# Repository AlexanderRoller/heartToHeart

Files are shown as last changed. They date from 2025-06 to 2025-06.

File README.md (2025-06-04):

# HeartToHeart

HeartToHeart is a hardware project designed for IoT prototyping, featuring a custom PCB and ESP32 microcontroller. The project includes AWS IoT integration, a custom display, and a complete KiCad design for fabrication and assembly.

## Features
- Custom PCB design (KiCad)
- ESP32 microcontroller
- AWS IoT Core connectivity
- OLED display (NHD-C12832A1Z-FSW-FBW-3V3)
- Example firmware for secure WiFi and AWS IoT connection

## Directory Structure
- `pcb/` – KiCad project files and backups
- `src/` – Firmware source code and secrets templates
- `pcb/media/` – Project images and schematic PDF

## Getting Started
1. **Clone the repository**
2. Copy `src/secrets.example.h` to `src/secrets.h` and fill in your WiFi and AWS IoT credentials
3. Open `pcb/pcb.kicad_pro` in KiCad to view or modify the PCB
4. Generate your own fabrication files (Gerbers, drills, etc.) using KiCad's plot and export tools
5. Flash the firmware in `src/src.ino` to your ESP32

## Images

### PCB Layout
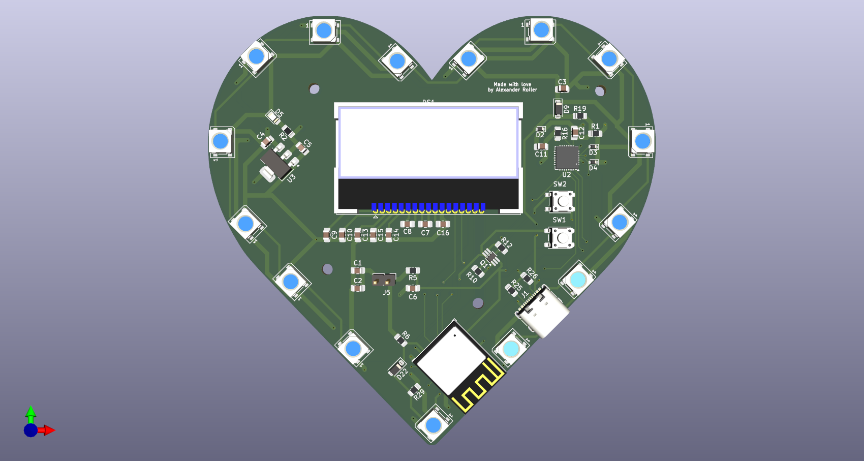
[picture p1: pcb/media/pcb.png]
PCB Layout


### Schematic
Schematic

## License
See `pcb/License.txt` for licensing information.

---

**Note:** Do not commit your real `src/secrets.h` with credentials. Use `src/secrets.example.h` as a template.

**Important:** Fabrication files (Gerbers, drills, etc.) are not included in the repository. You must generate your own using the provided KiCad project files.

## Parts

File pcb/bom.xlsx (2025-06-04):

Country of Origin may be different at time of shipment.
The HTSUS and ECCN information shown is for informational purposes only and is not a representation or warranty as to the accuracy or reliability of these classifications. All information is provided "as is" and is subject to change without notice. Any use made of the information provided is without recourse to Digi-Key and at the user's risk.
Index | Manufacturer Part Number | Manufacturer Name | Description | Availability | Stock Status | Attrition % | Requested Quantity 1 | Pack Quantity 1 | Pack Type 1 | Digi-Key Part Number 1 | Unit Price 1 | Extended Price 1 | Minimum Order Quantity 1 | Customer Reference | Requested Part Number | Lead Weeks | Datasheet | Reference Designator | US Import Tariff | Note | Part Status | RoHS Status | Moisture Sensitivity Level (MSL) | ECCN | HTSUS | Country of Origin | Environmental Information | Original Part numbers | REACH Status | Unit of Measure | Image | Product Notes
1 | ESP32-C6-MINI-1-N4 | Espressif Systems | RF TXRX MOD BT WIFI PCB TH SMD | 3,475 | In Stock |  | 1 | 1 | Cut Tape (CT) | 1965-ESP32-C6-MINI-1-N4CT-ND | 4.40000 | $4.40 | 1 |  | 1965-ESP32-C6-MINI-1-N4TR-ND | 8 | https://www.espressif.com/sites/default/files/documentation/esp32-c6-mini-1_mini-1u_datasheet_en.pdf |  | May apply on shipments to the U.S. |  | Active | Unknown | 3 (168 Hours) | 5A992C SC | 8517.62.0090 | China |  | 1965-ESP32-C6-MINI-1-N4TR-ND |  | EACH | https://mm.digikey.com/Volume0/opasdata/d220001/medias/images/4908/MFG_ESP32-C6-MINI-1-N4.jpg
2 | USB4105-GF-A | GCT | CONN RCP USB2.0 TYP C 24P SMD RA | 97,778 | In Stock |  | 1 | 1 | Cut Tape (CT) | 2073-USB4105-GF-ACT-ND | 0.78000 | $0.78 | 1 |  | 2073-USB4105-GF-ATR-ND | 9 | https://mm.digikey.com/Volume0/opasdata/d220001/medias/docus/5492/USB4105.pdf |  | May apply on shipments to the U.S. |  | Active | ROHS3 Compliant | 1 (Unlimited) | EAR99 | 8536.69.4040 | China | https://gct.co/files/info/gct_certificate_of_compliance.pdf | 2073-USB4105-GF-ATR-ND | REACH Unaffected | EACH | https://mm.digikey.com/Volume0/opasdata/d220001/medias/images/199/MFG_USB4105-GF-A.jpg
3 | 16347 | SparkFun Electronics | ADDRESS LED RED/GRN/BLUE | 34,175 | In Stock |  | 15 | 15 | Cut Tape (CT) | 1568-16347CT-ND | 0.68000 | $10.20 | 1 |  | 1568-16347TR-ND | 5 | https://cdn.sparkfun.com/datasheets/BreakoutBoards/WS2812B.pdf |  | N/A |  | Active | ROHS3 Compliant | 5A (24 Hours) | EAR99 | 8539.51.0000 | China |  | 1568-16347TR-ND | REACH Unaffected | EACH | https://mm.digikey.com/Volume0/opasdata/d220001/medias/images/4004/COM-16347.jpg
4 | BC847BDW1T1G | onsemi | TRANS 2NPN 45V 100MA SC88/SC70 | 135,970 | In Stock |  | 1 | 1 | Cut Tape (CT) | BC847BDW1T1GOSCT-ND | 0.18000 | $0.18 | 1 |  | BC847BDW1T1GOSCT-ND | 10 | https://www.onsemi.com/pdf/datasheet/bc846bdw1t1-d.pdf |  | May apply on shipments to the U.S. |  | Active | ROHS3 Compliant | 1 (Unlimited) | EAR99 | 8541.21.0075 | China | https://www.onsemi.com/site/pdf/RoHS-statement.pdf|https://www.onsemi.com/site/pdf/REACH-compliance-statement.pdf|https://www.onsemi.com/PowerSolutions/MaterialComposition.do?export=pdf&opnId=BC847BDW1T1G | BC847BDW1T1GOSCT-ND | REACH Unaffected | EACH | https://mm.digikey.com/Volume0/opasdata/d220001/medias/images/5883/488%7E419B-02%7EDF%2CDW%2CSQ%7E6-View-2.jpg
5 | CP2102N-A02-GQFN28 | Silicon Labs | IC USB TO UART BRIDGE QFN28 | 2,485 | In Stock |  | 1 | 1 | Tube | 336-5889-ND | 4.32000 | $4.32 | 1 |  | 336-5889-ND | 12 | https://www.silabs.com/documents/public/data-sheets/cp2102n-datasheet.pdf |  | N/A |  | Active | ROHS3 Compliant | 2 (1 Year) | EAR99 | 8542.39.0060 | Thailand |  | 336-5889-ND | REACH Unaffected | EACH | https://mm.digikey.com/Volume0/opasdata/d220001/medias/images/6222/336%7E28QFN-.80-5X5%7E%7E28.jpg
6 | AZ1117CH-3.3TRG1 | Diodes Incorporated | IC REG LINEAR 3.3V 1A SOT-223-3 | 39,920 | In Stock |  | 1 | 1 | Cut Tape (CT) | AZ1117CH-3.3TRG1DICT-ND | 0.16000 | $0.16 | 1 |  | AZ1117CH-3.3TRG1DITR-ND | 12 | https://www.diodes.com/assets/Datasheets/AZ1117C.pdf |  | May apply on shipments to the U.S. |  | Active | ROHS3 Compliant | 3 (168 Hours) | EAR99 | 8542.39.0060 | China | https://mm.digikey.com/Volume0/opasdata/d220001/medias/docus/6731/Diode%20RoHS3%20REACH%20247%20Jan%202025%20Statement.pdf | AZ1117CH-3.3TRG1DITR-ND | REACH Unaffected | EACH | https://mm.digikey.com/Volume0/opasdata/d220001/medias/images/4895/31%7ESOT223%7EE%2CG%2CH%7E4.JPG
7 | NHD-C12832A1Z-FSW-FBW-3V3 | Newhaven Display Intl | GRAPHIC DISPLAY FSTN BLACK (WHIT | 6,824 | In Stock |  | 1 | 1 | Bulk | NHD-C12832A1Z-FSW-FBW-3V3-ND | 12.78000 | $12.78 | 1 |  | NHD-C12832A1Z-FSW-FBW-3V3-ND | 18 | https://newhavendisplay.com/content/specs/NHD-C12832A1Z-FSW-FBW-3V3.pdf |  | May apply on shipments to the U.S. |  | Active | ROHS3 Compliant | Not Applicable | EAR99 | 8524.91.1000 | China |  | NHD-C12832A1Z-FSW-FBW-3V3-ND | REACH Unaffected | EACH | https://mm.digikey.com/Volume0/opasdata/d220001/medias/images/3503/MFG_NHD-C12832A1Z-FSW-FBW-3V3.jpg
8 | 1N5819HW-7-F | Diodes Incorporated | DIODE SCHOTTKY 40V 1A SOD123 | 358,770 | In Stock |  | 1 | 1 | Cut Tape (CT) | 1N5819HW-FDICT-ND | 0.25000 | $0.25 | 1 |  | 1N5819HW-FDITR-ND | 12 | https://www.diodes.com/assets/Datasheets/1N5819HW.pdf |  | May apply on shipments to the U.S. |  | Active | ROHS3 Compliant | 1 (Unlimited) | EAR99 | 8541.10.0080 | China | https://mm.digikey.com/Volume0/opasdata/d220001/medias/docus/6731/Diode%20RoHS3%20REACH%20247%20Jan%202025%20Statement.pdf | 1N5819HW-FDITR-ND | REACH Unaffected | EACH | https://mm.digikey.com/Volume0/opasdata/d220001/medias/images/5753/31%7ESOD123%7E%7E2-View-2.jpg
9 | GRM21BR61C106KE15K | Murata Electronics | CAP CER 10UF 16V X5R 0805 | 919,558 | In Stock |  | 4 | 4 | Cut Tape (CT) | 490-6473-1-ND | 0.14000 | $0.56 | 1 |  | 490-6473-2-ND | 10 | https://search.murata.co.jp/Ceramy/image/img/A01X/G101/ENG/GRM21BR61C106KE15-01.pdf |  | May apply on shipments to the U.S. |  | Active | ROHS3 Compliant | 1 (Unlimited) | EAR99 | 8532.24.0020 | China |  | 490-6473-2-ND | REACH Unaffected | EACH | https://mm.digikey.com/Volume0/opasdata/d220001/medias/images/5447/490-Ceramic-Capacitor-Tan-Field.jpg
10 | CC0805KRX7R9BB104 | YAGEO | CAP CER 0.1UF 50V X7R 0805 | 2,239,014 | In Stock |  | 1 | 1 | Cut Tape (CT) | 311-1140-1-ND | 0.08000 | $0.08 | 1 |  | 311-1140-2-ND | 16 | https://www.yageo.com/upload/media/product/productsearch/datasheet/mlcc/UPY-GPHC_X7R_6.3V-to-250V_24.pdf |  | N/A |  | Active | ROHS3 Compliant | 1 (Unlimited) | EAR99 | 8532.24.0020 | Taiwan |  | 311-1140-2-ND | REACH Unaffected | EACH | https://mm.digikey.com/Volume0/opasdata/d220001/medias/images/4322/cut-tape-render.jpg
11 | CL21B105KBFNNNE | Samsung Electro-Mechanics | CAP CER 1UF 50V X7R 0805 | 662,551 | In Stock |  | 10 | 10 | Cut Tape (CT) | 1276-1029-1-ND | 0.02400 | $0.24 | 1 |  | 1276-1029-2-ND | 22 | https://mm.digikey.com/Volume0/opasdata/d220001/medias/docus/609/CL21B105KBFNNNE_Spec.pdf |  | May apply on shipments to the U.S. |  | Active | ROHS3 Compliant | 1 (Unlimited) | EAR99 | 8532.24.0020 | China | https://www.samsungsem.com/files/fileDown.do?key=ed1dfdfa-645e-4252-b707-17f9b1502dd1|https://www.samsungsem.com/global/support/certificate/product-stewardship.do | 1276-1029-2-ND | REACH Unaffected | EACH | https://mm.digikey.com/Volume0/opasdata/d220001/medias/images/2537/Ceramic-Capacitor-CL-Series.jpg
12 | CL21A226MQQNNNE | Samsung Electro-Mechanics | CAP CER 22UF 6.3V X5R 0805 | 44,494 | In Stock |  | 1 | 1 | Cut Tape (CT) | 1276-1100-1-ND | 0.12000 | $0.12 | 1 |  | 1276-1100-2-ND | 22 | https://mm.digikey.com/Volume0/opasdata/d220001/medias/docus/5784/CL21A226MQQNNNE.pdf |  | N/A |  | Active | ROHS3 Compliant | 1 (Unlimited) | EAR99 | 8532.24.0020 | Philippines | https://www.samsungsem.com/files/fileDown.do?key=ed1dfdfa-645e-4252-b707-17f9b1502dd1|https://www.samsungsem.com/global/support/certificate/product-stewardship.do | 1276-1100-2-ND | REACH Unaffected | EACH | https://mm.digikey.com/Volume0/opasdata/d220001/medias/images/2537/Ceramic-Capacitor-CL-Series.jpg
13 | ESD5B5.0ST1G | onsemi | TVS DIODE 5VWM SOD523 | 28,881 | In Stock |  | 3 | 3 | Cut Tape (CT) | ESD5B5.0ST1GOSCT-ND | 0.23000 | $0.69 | 1 |  | ESD5B5.0ST1G | 10 | https://www.onsemi.com/pdf/datasheet/esd5b5.0st1-d.pdf |  | May apply on shipments to the U.S. |  | Active | ROHS3 Compliant | 1 (Unlimited) | EAR99 | 8541.10.0080 | China | https://www.onsemi.com/site/pdf/RoHS-statement.pdf|https://www.onsemi.com/PowerSolutions/MaterialComposition.do?export=pdf&opnId=ESD5B5.0ST1G | ESD5B5.0ST1G | REACH Unaffected | EACH | https://mm.digikey.com/Volume0/opasdata/d220001/medias/images/5883/488%7E502-01%7E%7E2-View-2.jpg
14 | LTST-C171KRKT | Lite-On Inc. | LED RED CLEAR SMD | 207,705 | In Stock |  | 1 | 1 | Cut Tape (CT) | 160-1427-1-ND | 0.15000 | $0.15 | 1 |  | LTST-C171KRKT | 18 | https://optoelectronics.liteon.com/upload/download/DS22-2000-109/LTST-C171KRKT.pdf |  | May apply on shipments to the U.S. |  | Active | ROHS3 Compliant | 2A (4 Weeks) | EAR99 | 8541.41.0000 | China |  | LTST-C171KRKT | REACH Unaffected | EACH | https://mm.digikey.com/Volume0/opasdata/d220001/medias/images/1117/LTST-C171TBKT%2CLTST-C171KGKT%2CLTST-C171KRKT.jpg
15 | RK73H2ATTD4752F | KOA Speer Electronics, Inc. | RES 47.5K OHM 1% 1/4W 0805 | 46,082 | In Stock |  | 1 | 1 | Cut Tape (CT) | 2019-RK73H2ATTD4752FCT-ND | 0.10000 | $0.10 | 1 |  | RK73H2ATTD4752F | 7 | https://www.koaspeer.com/pdfs/RK73H.pdf |  | N/A |  | Active | ROHS3 Compliant | 1 (Unlimited) | EAR99 | 8533.21.0030 | Malaysia | https://www.koaglobal.com/-/media/Files/KOA_Global/product/common/rohs/Certificate_of_RoHS_Compliance_July2024.pdf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|https://mm.digikey.com/Volume0/opasdata/d220001/medias/docus/5718/2019_KOA%20Speer%20RoHS3%20Statement.pdf | RK73H2ATTD4752F | REACH Unaffected | EACH | https://mm.digikey.com/Volume0/opasdata/d220001/medias/images/5572/MFG_RK73H1HTTCM12R7D.jpg
16 | RC0805JR-075K1L | YAGEO | RES 5.1K OHM 5% 1/8W 0805 | 494,728 | In Stock |  | 3 | 3 | Cut Tape (CT) | 311-5.1KARCT-ND | 0.10000 | $0.30 | 1 |  | RC0805JR-075K1L | 18 | https://www.yageo.com/upload/media/product/products/datasheet/rchip/PYu-RC_Group_51_RoHS_L_12.pdf |  | N/A |  | Active | ROHS3 Compliant | 1 (Unlimited) | EAR99 | 8533.21.0030 | Taiwan | https://www.yageo.com/en/Download/Index/certificates#rchip | RC0805JR-075K1L | REACH Unaffected | EACH | https://mm.digikey.com/Volume0/opasdata/d220001/medias/images/4848/13_0805-%282012-metric%29.jpg
17 | RR1220P-103-D | Susumu | RES SMD 10K OHM 0.5% 1/10W 0805 | 1,455,099 | In Stock |  | 10 | 10 | Cut Tape (CT) | RR12P10.0KDCT-ND | 0.03100 | $0.31 | 1 |  | RR1220P-103-D | 22 | https://www.susumu.co.jp/common/pdf/n_catalog_partition05_en.pdf |  | N/A |  | Active | ROHS3 Compliant | 1 (Unlimited) | EAR99 | 8533.21.0030 | Japan | https://www.susumu.co.jp/common/pdf/Certificate%20of%20EU%20RoHS%20compliance.pdf | RR1220P-103-D | REACH Unaffected | EACH | https://mm.digikey.com/Volume0/opasdata/d220001/medias/images/4322/cut-tape-render.jpg
18 | RC0805FR-073K3L | YAGEO | RES 3.3K OHM 1% 1/8W 0805 | 901,553 | In Stock |  | 1 | 1 | Cut Tape (CT) | 311-3.30KCRCT-ND | 0.10000 | $0.10 | 1 |  | RC0805FR-073K3L | 18 | https://www.yageo.com/upload/media/product/products/datasheet/rchip/PYu-RC_Group_51_RoHS_L_12.pdf |  | N/A |  | Active | ROHS3 Compliant | 1 (Unlimited) | EAR99 | 8533.21.0030 | Taiwan | https://www.yageo.com/en/Download/Index/certificates#rchip | RC0805FR-073K3L | REACH Unaffected | EACH | https://mm.digikey.com/Volume0/opasdata/d220001/medias/images/4322/cut-tape-render.jpg
19 | RC0805FR-071KL | YAGEO | RES 1K OHM 1% 1/8W 0805 | 538,792 | In Stock |  | 1 | 1 | Cut Tape (CT) | 311-1.00KCRCT-ND | 0.10000 | $0.10 | 1 |  | RC0805FR-071KL | 18 | https://www.yageo.com/upload/media/product/products/datasheet/rchip/PYu-RC_Group_51_RoHS_L_12.pdf |  | N/A |  | Active | ROHS3 Compliant | 1 (Unlimited) | EAR99 | 8533.21.0030 | Taiwan | https://www.yageo.com/en/Download/Index/certificates#rchip | RC0805FR-071KL | REACH Unaffected | EACH | https://mm.digikey.com/Volume0/opasdata/d220001/medias/images/4322/cut-tape-render.jpg
20 | RMCF0805FT22K1 | Stackpole Electronics Inc | RES 22.1K OHM 1% 1/8W 0805 | 561,751 | In Stock |  | 1 | 1 | Cut Tape (CT) | RMCF0805FT22K1CT-ND | 0.10000 | $0.10 | 1 |  | RMCF0805FT22K1 | 16 | https://www.seielect.com/catalog/sei-rmcf_rmcp.pdf |  | May apply on shipments to the U.S. |  | Active | ROHS3 Compliant | 1 (Unlimited) | EAR99 | 8533.21.0030 | China | https://www.seielect.com/catalog/SEI-RoHS_Compliance_Status.pdf|https://www.seielect.com/catalog/reach.pdf|https://www.seielect.com/catalog/sei-coc%20prop%2065.pdf | RMCF0805FT22K1 | REACH Unaffected | EACH | https://mm.digikey.com/Volume0/opasdata/d220001/medias/images/2597/MFG_RMC%20SERIES.jpg
21 | PTS647SK38SMTR2 LFS | C&K | SWITCH TACTILE SPST-NO 0.05A 12V | 6,281 | In Stock |  | 2 | 2 | Cut Tape (CT) | PTS647SK38SMTR2LFSCT-ND | 0.26000 | $0.52 | 1 |  | PTS647SK38SMTR2 LFS | 11 | https://www.ckswitches.com/media/2567/pts647.pdf |  | May apply on shipments to the U.S. |  | Active | ROHS3 Compliant | 1 (Unlimited) | EAR99 | 8536.50.9031 | China |  | PTS647SK38SMTR2 LFS | REACH Unaffected | EACH | https://mm.digikey.com/Volume0/opasdata/d220001/medias/images/693/MFG_PTS647SK38SMTR2LFS.jpg
22 | 1N4148W-7-F | Diodes Incorporated | DIODE STANDARD 100V 150MA SOD123 | 1,059,605 | In Stock |  | 1 | 1 | Cut Tape (CT) | 1N4148W-FDICT-ND | 0.11000 | $0.11 | 1 | 1 | 1N4148W-7-F | 12 | https://www.diodes.com/assets/Datasheets/BAV16W_1N4148W.pdf |  | May apply on shipments to the U.S. |  | Active | ROHS3 Compliant | 1 (Unlimited) | EAR99 | 8541.10.0070 | China | https://mm.digikey.com/Volume0/opasdata/d220001/medias/docus/6731/Diode%20RoHS3%20REACH%20247%20Jan%202025%20Statement.pdf | 1N4148W-7-F | REACH Unaffected | EACH | https://mm.digikey.com/Volume0/opasdata/d220001/medias/images/5753/31%7ESOD123%7E%7E2-View-2.jpg
23 | SPC02SYAN | Sullins Connector Solutions | CONN JUMPER SHORTING GOLD FLASH | 464,649 | In Stock |  | 1 | 1 | Bulk | S9001-ND | 0.10000 | $0.10 | 1 |  | SPC02SYAN | 11 | https://drawings-pdf.s3.amazonaws.com/11134.pdf |  | N/A |  | Active | ROHS3 Compliant | 1 (Unlimited) | EAR99 | 8538.90.8180 | Taiwan | https://www.sullinscorp.com/wp-content/uploads/2019/03/Sullins-RoHS-Compliant-Statement.pdf|https://www.sullinscorp.com/wp-content/uploads/2025/02/Sullins-REACH-247-SVHC-Compliant-Statement.pdf | SPC02SYAN | REACH Unaffected | EACH | https://mm.digikey.com/Volume0/opasdata/d220001/medias/images/2582/STC02SYAN%2C%20SSC02SYAN%2C%20SPC02SYAN.jpg

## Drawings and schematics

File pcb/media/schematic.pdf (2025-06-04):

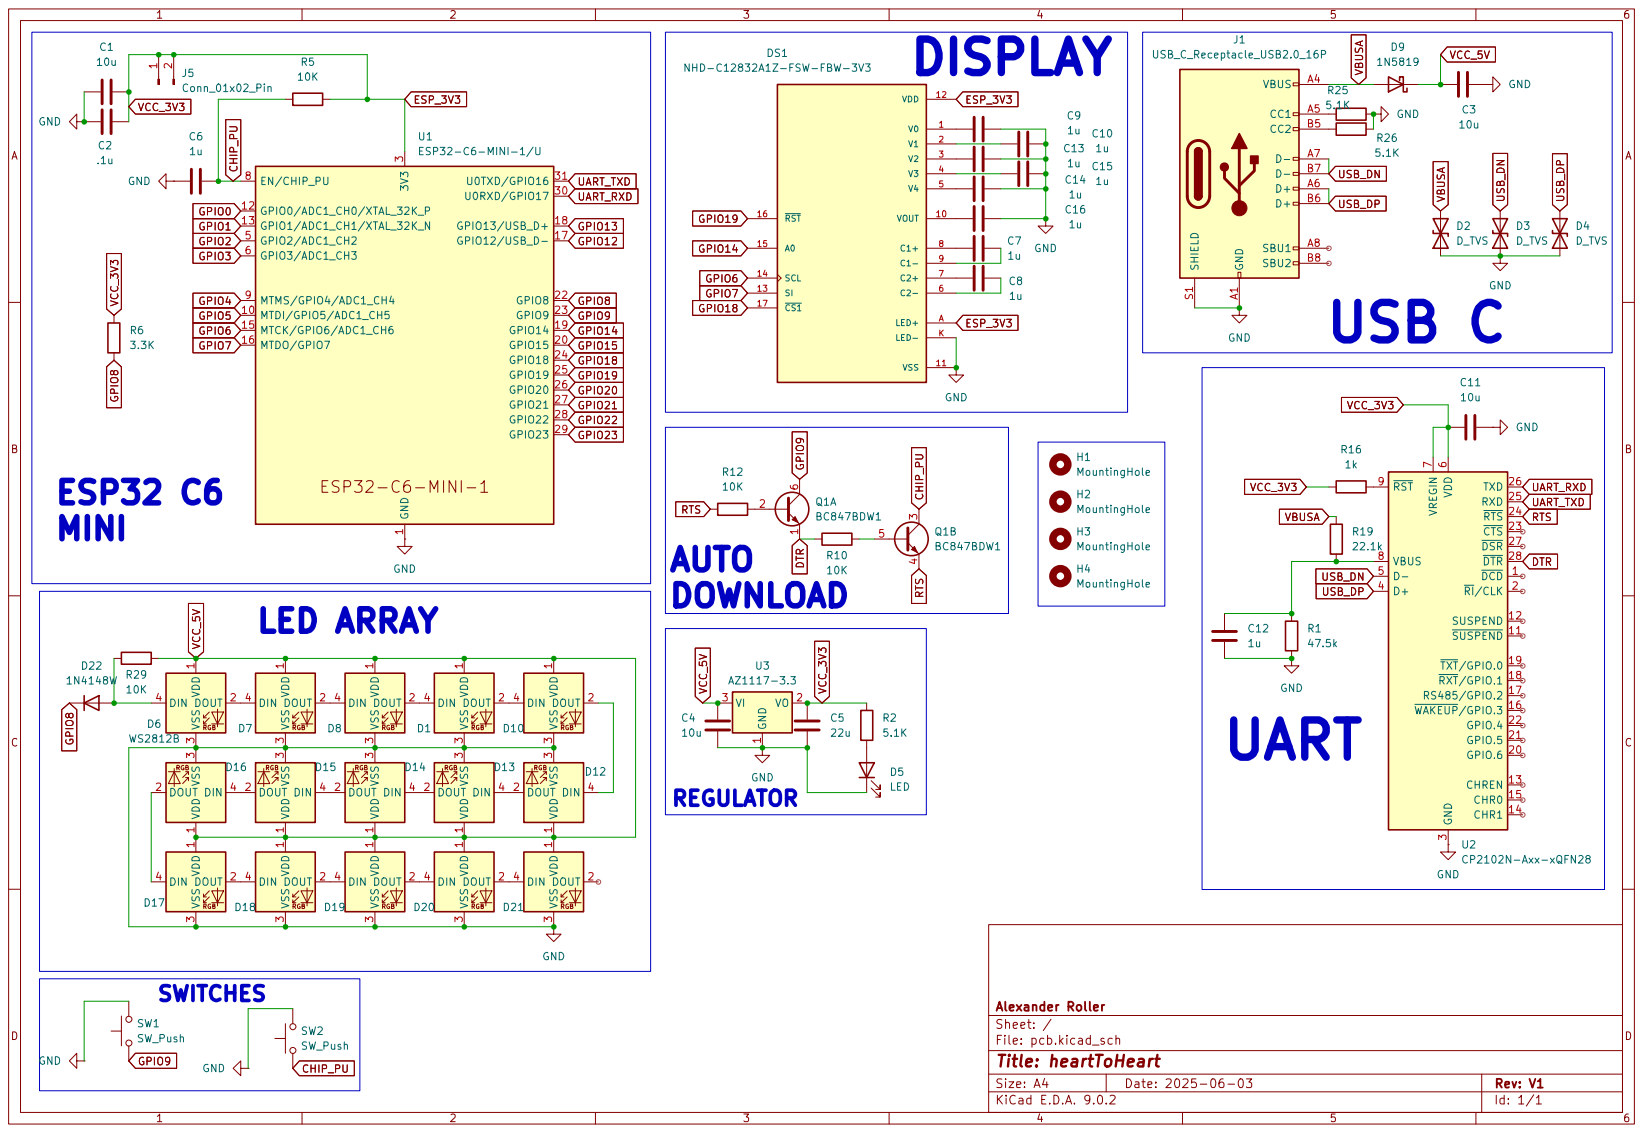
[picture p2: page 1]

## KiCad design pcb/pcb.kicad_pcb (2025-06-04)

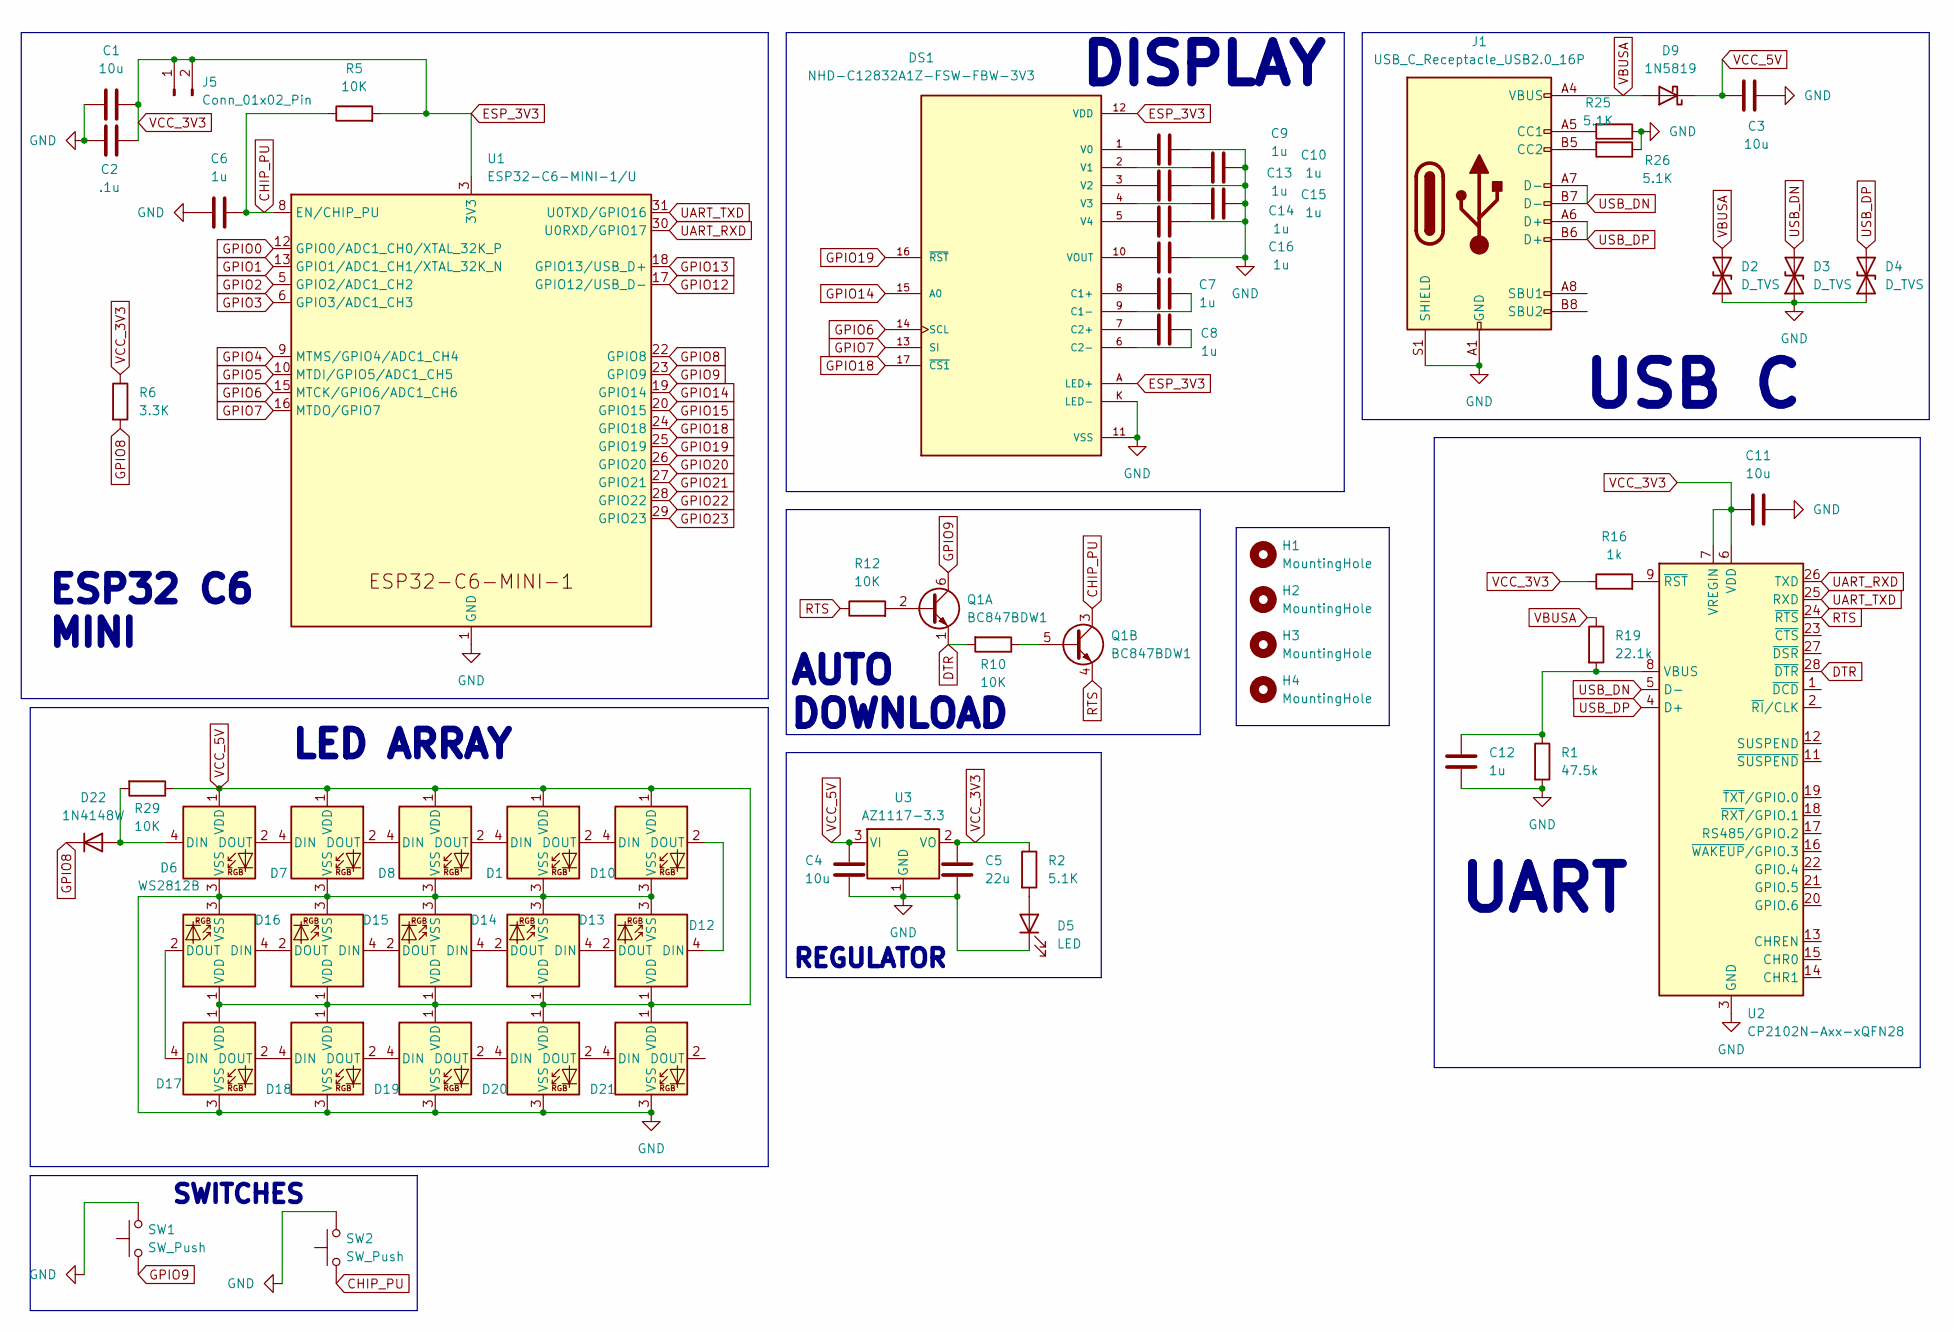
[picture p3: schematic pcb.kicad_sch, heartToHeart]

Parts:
C1, C3, C4, C11: 10u; C_0805_2012Metric_Pad1.18x1.45mm_HandSolder
C2: .1u; C_0805_2012Metric_Pad1.18x1.45mm_HandSolder
C5: 22u; C_0805_2012Metric_Pad1.18x1.45mm_HandSolder
C6, C7, C8, C9, C10, C12, C13, C14, C15, C16: 1u; C_0805_2012Metric_Pad1.18x1.45mm_HandSolder
D1, D6, D7, D8, D10, D12, D13, D14, D15, D16, D17, D18, D19, D20, D21: WS2812B; LED_WS2812B_PLCC4_5.0x5.0mm_P3.2mm
D2, D3, D4: D_TVS; D_SOD-523
D5: LED; LED_0805_2012Metric_Pad1.15x1.40mm_HandSolder
D9: 1N5819; D_SOD-123
D22: 1N4148W; D_SOD-123
DS1: NHD-C12832A1Z-FSW-FBW-3V3; NHD-C12832A1Z-FSRGB; PARTREV 7; DigiKey_Part_Number NHD-C12832A1Z-FSW-FBW-3V3-ND
H1, H2, H3, H4: MountingHole; MountingHole_2.5mm
J1: USB_C_Receptacle_USB2.0_16P; USB_C_Receptacle_GCT_USB4105-xx-A_16P_TopMnt_Horizontal
J5: Conn_01x02_Pin; PinHeader_1x02_P2.54mm_Vertical
Q1: BC847BDW1; SOT-363_SC-70-6_Handsoldering
R1: 47.5k; R_0805_2012Metric_Pad1.20x1.40mm_HandSolder
R2, R25, R26: 5.1K; R_0805_2012Metric_Pad1.20x1.40mm_HandSolder
R5, R10, R12, R29: 10K; R_0805_2012Metric_Pad1.20x1.40mm_HandSolder
R6: 3.3K; R_0805_2012Metric_Pad1.20x1.40mm_HandSolder
R16: 1k; R_0805_2012Metric_Pad1.20x1.40mm_HandSolder
R19: 22.1k; R_0805_2012Metric_Pad1.20x1.40mm_HandSolder
SW1, SW2: SW_Push; SW_SPST_PTS647_Sx38
U1: ESP32-C6-MINI-1/U; ESP32-C6-MINI-1
U2: CP2102N-Axx-xQFN28; QFN-28-1EP_5x5mm_P0.5mm_EP3.25x3.25mm
U3: AZ1117-3.3; SOT-223-3_TabPin2

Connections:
CHIP_PU: C6.2, Q1.3 (C2), R5.1, SW2.1, U1.8 (EN/CHIP_PU)
DTR: Q1.1 (E1), R10.2, U2.28 (~DTR)
ESP_3V3: C1.2, C2.2, C5.1, C11.1, DS1.12 (VDD), DS1.A (LED+), J5.1, J5.2, R2.1, R5.2, R6.1, R16.1, U1.3 (3V3), U2.6 (VDD), U2.7 (VREGIN), U3.2 (VO)
GND: C1.1, C2.1, C3.2, C4.2, C5.2, C6.1, C9.2, C10.2, C11.2, C12.1, C13.2, C14.2, C15.2, C16.2, D1.3 (VSS), D2.1 (A1), D3.1 (A1), D4.1 (A1), D5.1 (K), D6.3 (VSS), D7.3 (VSS), D8.3 (VSS), D10.3 (VSS), D12.3 (VSS), D13.3 (VSS), D14.3 (VSS), D15.3 (VSS), D16.3 (VSS), D17.3 (VSS), D18.3 (VSS), D19.3 (VSS), D20.3 (VSS), D21.3 (VSS), DS1.11 (VSS), DS1.K (LED-), J1.A1 (GND), J1.A12 (GND), J1.B1 (GND), J1.B12 (GND), J1.S1 (SHIELD), R1.2, R25.1, R26.1, SW1.2, SW2.2, U1.1 (GND), U1.2 (GND), U1.11 (GND), U1.14 (GND), U1.36 (GND), U1.37 (GND), U1.38 (GND), U1.39 (GND), U1.40 (GND), U1.41 (GND), U1.42 (GND), U1.43 (GND), U1.44 (GND), U1.45 (GND), U1.46 (GND), U1.47 (GND), U1.48 (GND), U1.49 (GND), U1.50 (GND), U1.51 (GND), U1.52 (GND), U1.53 (GND), U2.3 (GND), U2.29 (GND), U3.1 (GND)
GPIO0: U1.12 (GPIO0/ADC1_CH0/XTAL_32K_P)
GPIO1: U1.13 (GPIO1/ADC1_CH1/XTAL_32K_N)
GPIO2: U1.5 (GPIO2/ADC1_CH2)
GPIO3: U1.6 (GPIO3/ADC1_CH3)
GPIO4: U1.9 (MTMS/GPIO4/ADC1_CH4)
GPIO5: U1.10 (MTDI/GPIO5/ADC1_CH5)
GPIO6: DS1.14 (SCL), U1.15 (MTCK/GPIO6/ADC1_CH6)
GPIO7: DS1.13 (SI), U1.16 (MTDO/GPIO7)
GPIO8: D22.1 (K), R6.2, U1.22 (GPIO8)
GPIO9: Q1.6 (C1), SW1.1, U1.23 (GPIO9)
GPIO12: U1.17 (GPIO12/USB_D-)
GPIO13: U1.18 (GPIO13/USB_D+)
GPIO14: DS1.15 (A0), U1.19 (GPIO14)
GPIO15: U1.20 (GPIO15)
GPIO18: DS1.17 (~CS1), U1.24 (GPIO18)
GPIO19: DS1.16 (~RST), U1.25 (GPIO19)
GPIO20: U1.26 (GPIO20)
GPIO21: U1.27 (GPIO21)
GPIO22: U1.28 (GPIO22)
GPIO23: U1.29 (GPIO23)
unnamed: D1.4 (DIN), D8.2 (DOUT)
unnamed: D1.2 (DOUT), D10.4 (DIN)
unnamed: D5.2 (A), R2.2
unnamed: D6.2 (DOUT), D7.4 (DIN)
unnamed: D7.2 (DOUT), D8.4 (DIN)
unnamed: D10.2 (DOUT), D12.4 (DIN)
unnamed: D12.2 (DOUT), D13.4 (DIN)
unnamed: D13.2 (DOUT), D14.4 (DIN)
unnamed: D14.2 (DOUT), D15.4 (DIN)
unnamed: D15.2 (DOUT), D16.4 (DIN)
unnamed: D16.2 (DOUT), D17.4 (DIN)
unnamed: D17.2 (DOUT), D18.4 (DIN)
unnamed: D18.2 (DOUT), D19.4 (DIN)
unnamed: D19.2 (DOUT), D20.4 (DIN)
unnamed: D20.2 (DOUT), D21.4 (DIN)
unnamed: D6.4 (DIN), D22.2 (A), R29.2
unnamed: C7.1, DS1.8 (C1+)
unnamed: C7.2, DS1.9 (C1-)
unnamed: C8.1, DS1.7 (C2+)
unnamed: C8.2, DS1.6 (C2-)
unnamed: C9.1, DS1.1 (V0)
unnamed: C10.1, DS1.2 (V1)
unnamed: C13.1, DS1.3 (V2)
unnamed: C15.1, DS1.4 (V3)
unnamed: C14.1, DS1.5 (V4)
unnamed: C16.1, DS1.10 (VOUT)
unnamed: J1.A5 (CC1), R25.2
unnamed: J1.B5 (CC2), R26.2
unnamed: Q1.2 (B1), R12.2
unnamed: Q1.5 (B2), R10.1
unnamed: C12.2, R1.1, R19.2, U2.8 (VBUS)
unnamed: R16.2, U2.9 (~RST)
RTS: Q1.4 (E2), R12.1, U2.24 (~RTS)
UART_RXD: U1.30 (U0RXD/GPIO17), U2.26 (TXD)
UART_TXD: U1.31 (U0TXD/GPIO16), U2.25 (RXD)
USB_DN: D3.2 (A2), J1.A7 (D-), J1.B7 (D-), U2.5 (D-)
USB_DP: D4.2 (A2), J1.A6 (D+), J1.B6 (D+), U2.4 (D+)
VBUSA: D2.2 (A2), D9.2 (A), J1.A4 (VBUS), J1.A9 (VBUS), J1.B4 (VBUS), J1.B9 (VBUS), R19.1
VCC_5V: C3.1, C4.1, D1.1 (VDD), D6.1 (VDD), D7.1 (VDD), D8.1 (VDD), D9.1 (K), D10.1 (VDD), D12.1 (VDD), D13.1 (VDD), D14.1 (VDD), D15.1 (VDD), D16.1 (VDD), D17.1 (VDD), D18.1 (VDD), D19.1 (VDD), D20.1 (VDD), D21.1 (VDD), R29.1, U3.3 (VI)

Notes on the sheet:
LED ARRAY
ESP32 C6 MINI
UART
REGULATOR
SWITCHES
DISPLAY
AUTO DOWNLOAD
USB C

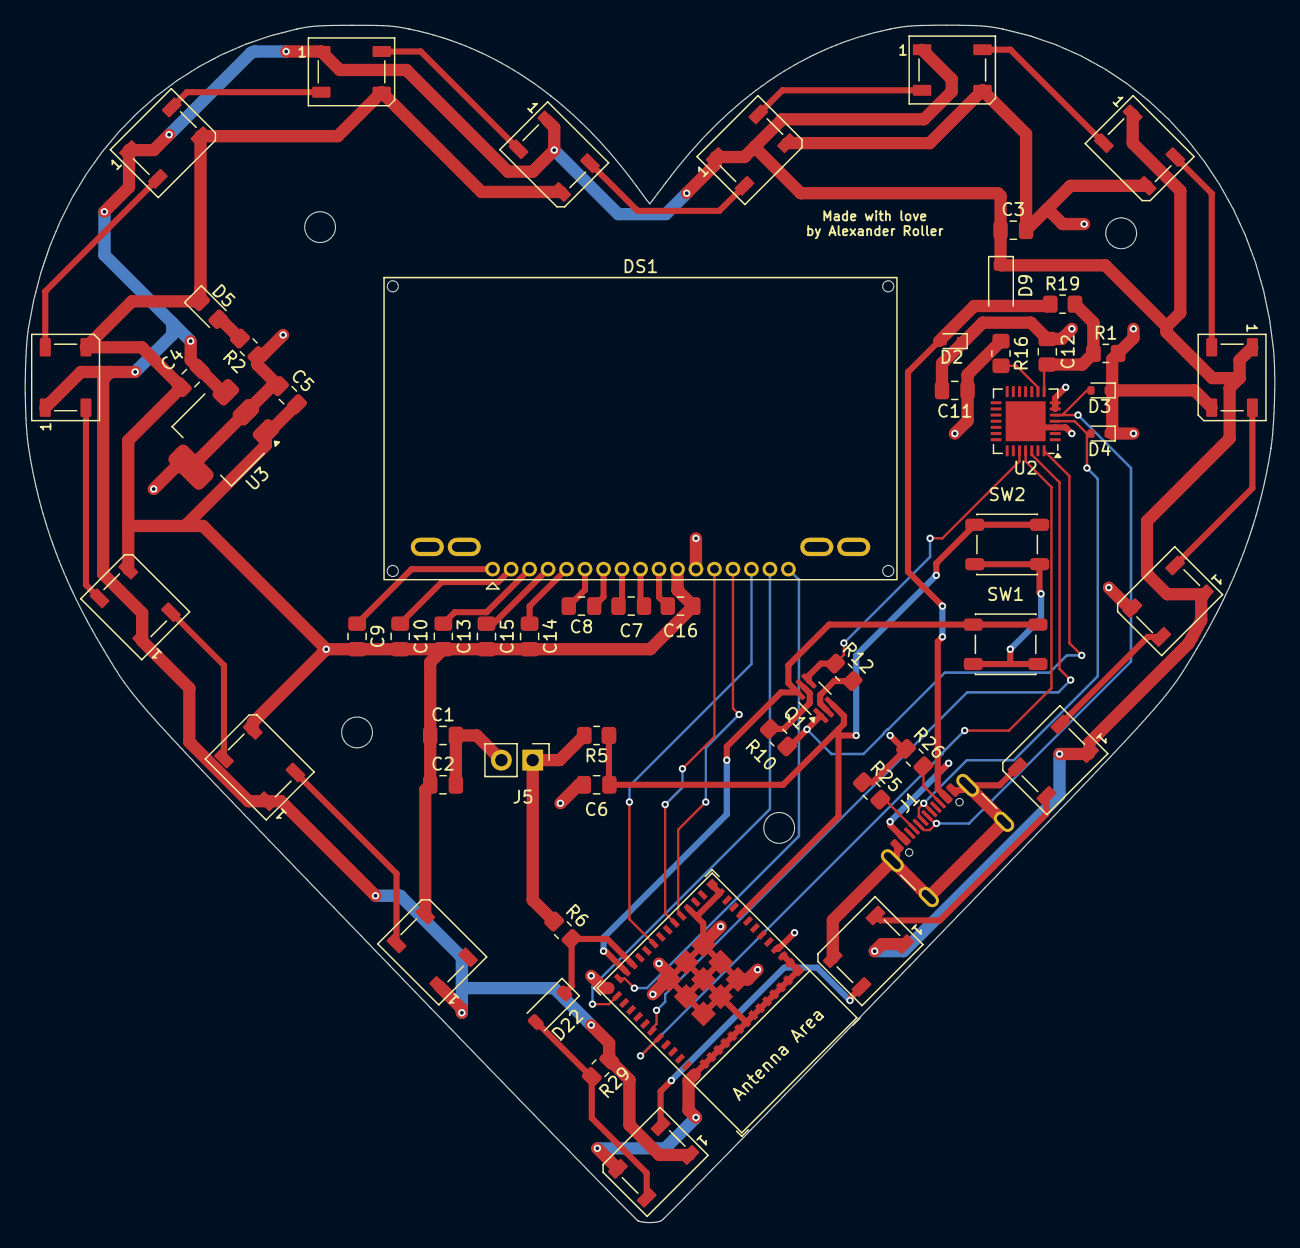
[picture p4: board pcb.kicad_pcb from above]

Board: 4 copper layers, 101.4 x 97.2 mm, 61 parts (0 on the bottom side), 50 nets.

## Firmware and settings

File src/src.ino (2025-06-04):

#include "secrets.h"
#include <WiFiClientSecure.h>
#include <MQTTClient.h>
#include <ArduinoJson.h>
#include "WiFi.h"
#include <math.h>

// global BPM variable
float bpm = 80.0f;

// FastLED
#include <FastLED.h>
#define NUM_LEDS 1
#define DATA_PIN 8
CRGB leds[NUM_LEDS];

// mqtt topics
#define AWS_IOT_SUBSCRIBE_TOPIC "hr/test"

WiFiClientSecure net = WiFiClientSecure();
MQTTClient client = MQTTClient(256);

void connectAWS()
{
  WiFi.mode(WIFI_STA);
  WiFi.begin(WIFI_SSID, WIFI_PASSWORD);

  Serial.print("Connecting to WiFi");

  while (WiFi.status() != WL_CONNECTED)
  {
    delay(500);
    Serial.print(".");
  }
  Serial.println();
  // use AWS credentials
  net.setCACert(AWS_CERT_CA);
  net.setCertificate(AWS_CERT_CRT);
  net.setPrivateKey(AWS_CERT_PRIVATE);

  // connect to AWS
  client.begin(AWS_IOT_ENDPOINT, 8883, net);

  // message handler
  client.onMessage(messageHandler);

  Serial.println("Connecting to AWS IoT");

  while (!client.connect(THINGNAME))
  {
    Serial.print(".");
    delay(1000);
  }

  if (!client.connected())
  {
    Serial.println("Failed to connect to AWS IoT");
    return;
  }

  // subscribe to topic
  bool ok = client.subscribe(AWS_IOT_SUBSCRIBE_TOPIC);
  Serial.printf("Subscribe to “%s”: %s\n", AWS_IOT_SUBSCRIBE_TOPIC, ok ? "OK" : "FAIL");

  Serial.println("Connected to AWS IoT");
}

void messageHandler(String &topic, String &payload)
{
  Serial.println("incoming: " + topic + " - " + payload);

  StaticJsonDocument<200> doc;
  DeserializationError error = deserializeJson(doc, payload);
  if (error) {
    Serial.print("deserializeJson() failed: ");
    Serial.println(error.c_str());
    return;
  }

  // update the global bpm
  bpm = doc["bpm"].as<float>();
  Serial.print("Updated global BPM: ");
  Serial.println(bpm);

}

void setup()
{
  Serial.begin(115200);

  FastLED.addLeds<NEOPIXEL, DATA_PIN>(leds, NUM_LEDS);

  connectAWS();
}

void loop()
{
  client.loop();
  wave(int(bpm));
}

void blink(float freq){  
  // freq is in cycles per minute, so one cycle = 60000 ms / freq
  float periodMs = 60000.0f / freq;      
  float halfPeriod = periodMs / 2.0f;    // on for half cycle, off for half cycle

  // turn LED(s) on
  for (int i = 0; i < NUM_LEDS; i++) {
    leds[i] = CRGB::Red;
  }
  FastLED.show();
  delay((uint32_t)halfPeriod);

  // turn LED(s) off
  for (int i = 0; i < NUM_LEDS; i++) {
    leds[i] = CRGB::Black;
  }
  FastLED.show();
  delay((uint32_t)halfPeriod);
}

void wave(int freq) {
  // non-blocking sine-wave pulsing based on millis()
  static float angle = 0.0f;
  static int prevFreq = -1;
  static unsigned long lastMs = 0;
  const float twoPi = 6.28318530718f;
  unsigned long now = millis();

  // reset phase when frequency changes
  if (freq != prevFreq) {
    angle = 0.0f;
    prevFreq = freq;
    lastMs = now;
  }

  // advance phase by elapsed time
  unsigned long dt = now - lastMs;
  float periodMs = 60000.0f / (float)freq;
  angle += twoPi * dt / periodMs;
  if (angle >= twoPi) angle -= twoPi;

  // compute brightness and update LED
  uint8_t bright = (uint8_t)(255.0f * (0.5f + 0.5f * sin(angle)));
  FastLED.setBrightness(bright);
  leds[0] = CRGB::Red;
  FastLED.show();

  lastMs = now;
}
